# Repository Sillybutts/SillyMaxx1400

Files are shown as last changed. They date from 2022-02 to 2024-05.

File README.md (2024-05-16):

# SillyMaxx 1400

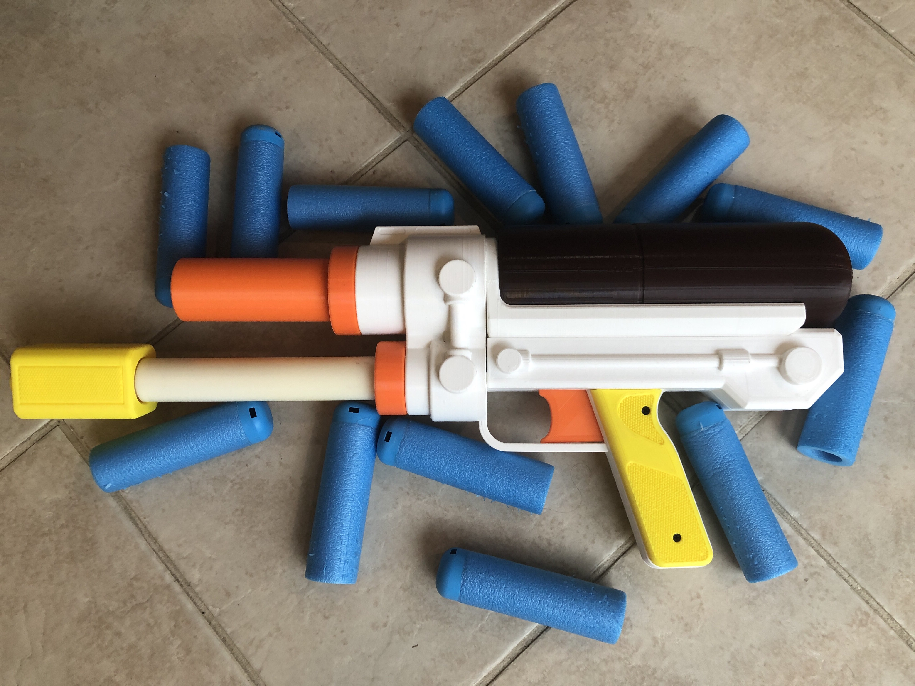
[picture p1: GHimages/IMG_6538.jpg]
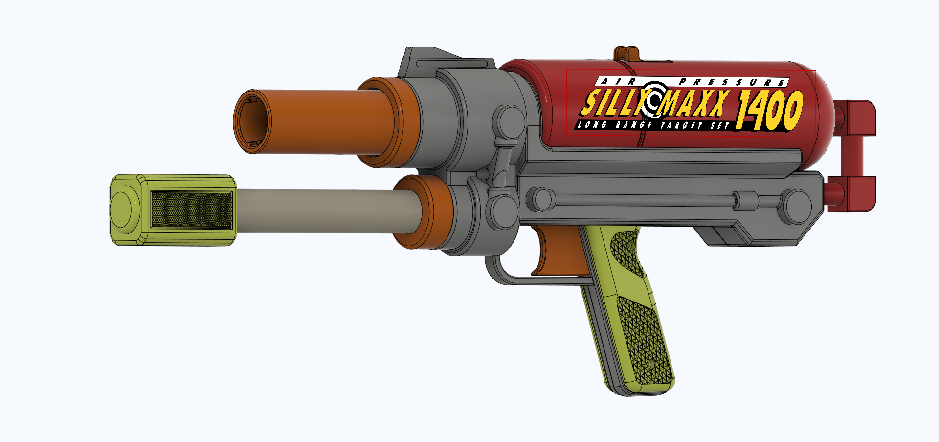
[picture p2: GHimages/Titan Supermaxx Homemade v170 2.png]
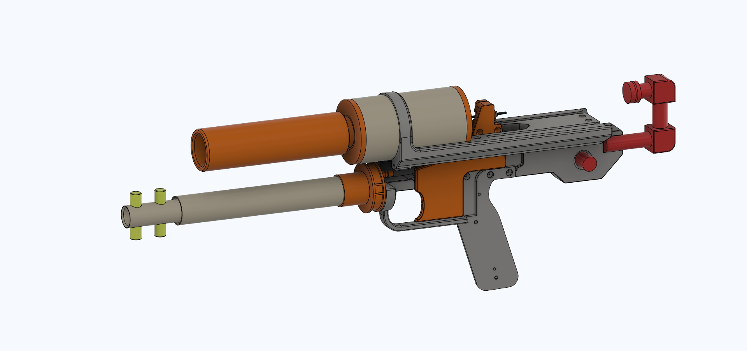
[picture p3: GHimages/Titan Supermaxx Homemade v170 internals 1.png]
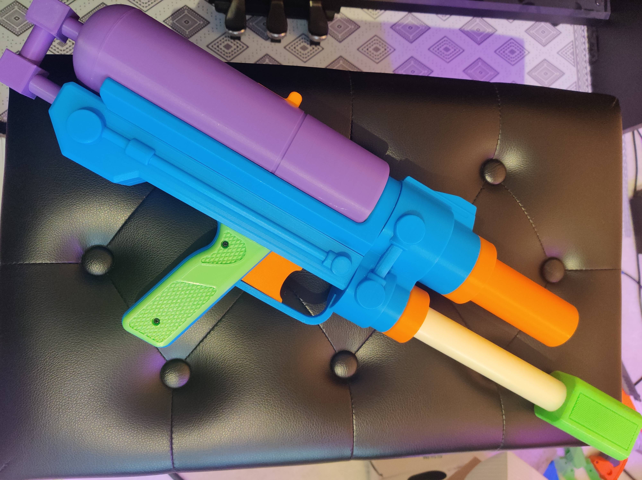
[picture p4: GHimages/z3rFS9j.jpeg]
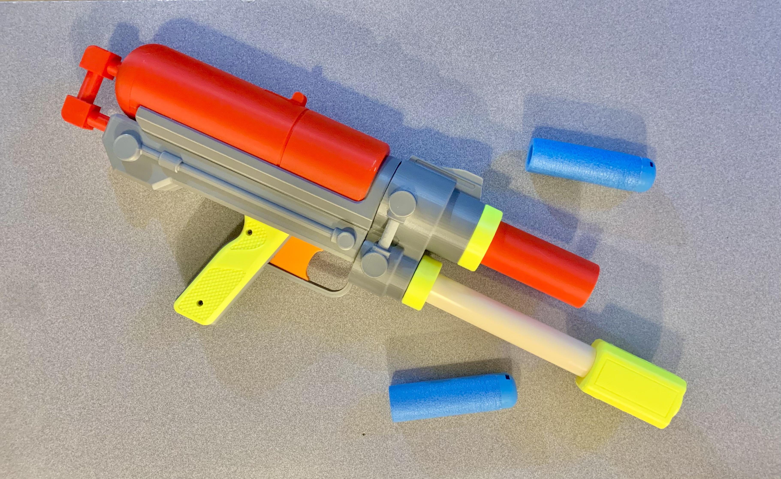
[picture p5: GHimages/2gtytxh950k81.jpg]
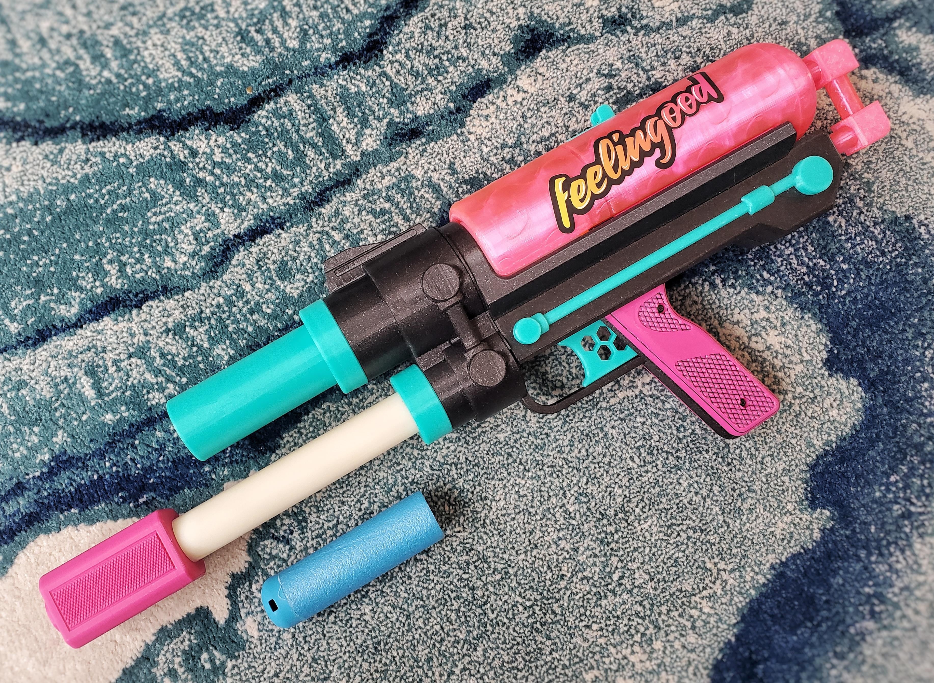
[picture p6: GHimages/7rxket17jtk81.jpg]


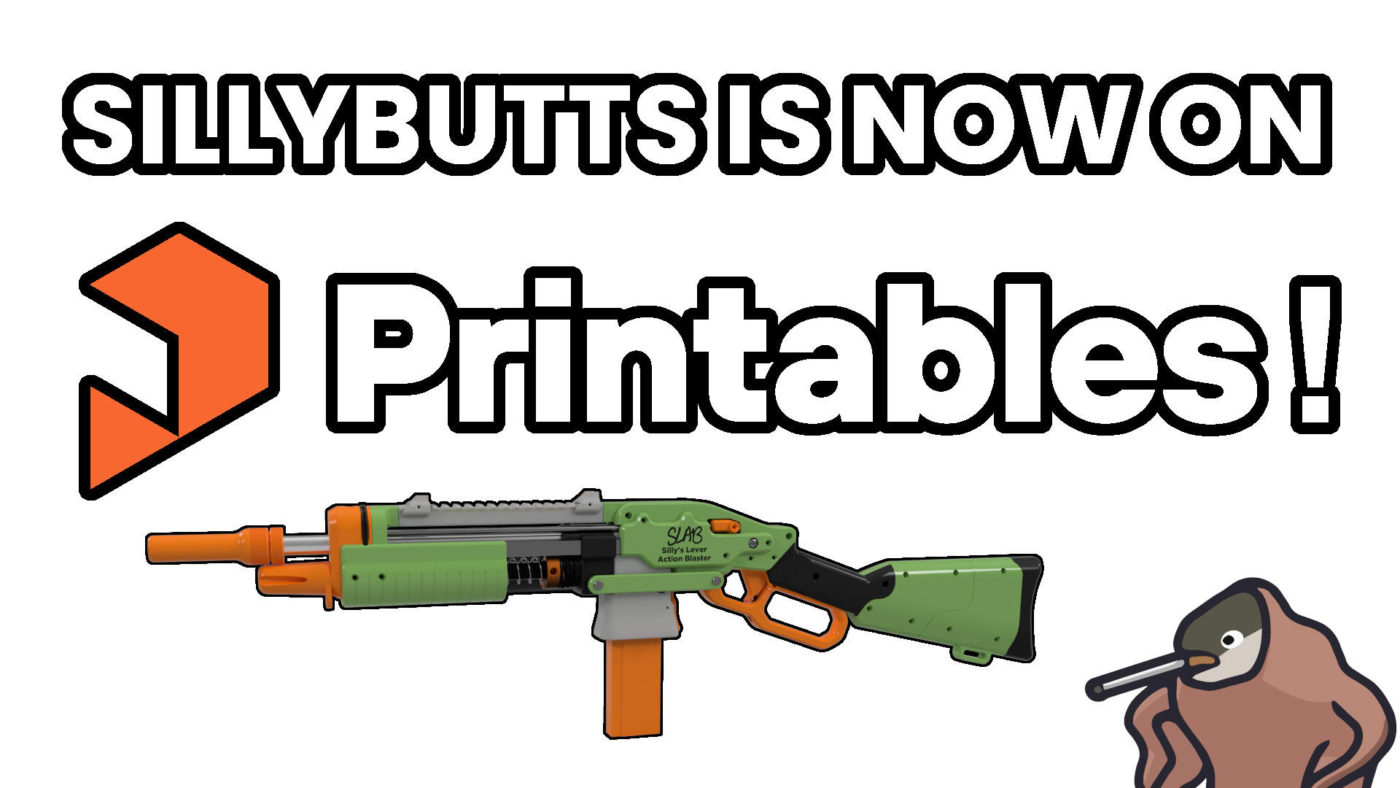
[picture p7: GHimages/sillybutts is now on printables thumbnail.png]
Printables Button


## I ALSO UPLOAD TO PRINTABLES https://www.printables.com/model/876191-sillymaxx-1400-nerf-titan-reshell

### Changelog:
4/14/22: Added a split version of BodyBlockC. There is now BodyBlockC, BodyBlockCFront, and BodyBlockCBack.

## Description

Basic assembly guide: https://www.youtube.com/watch?v=TCJiuXc-gHQ

1 minute firing demo: https://www.youtube.com/watch?v=Evi2LHyZtMM

1 minute blaster overview: https://www.youtube.com/watch?v=Qa94QIY8Uhg

The hall of finished blasters:
- Mine (Sillybutts) https://www.youtube.com/watch?v=uj7RobxyauM
- u/nick_la_plante https://www.reddit.com/r/Nerf/comments/t17dpy/finally_got_around_to_assembling_my_own/
- u/djnobility https://www.reddit.com/r/Nerf/comments/t4f6s7/the_sillymaxx_1400_has_me_feeling_good/
- u/Shaznazabbadaz https://www.reddit.com/r/Nerf/comments/t68buf/my_sillymaxx_1400_inspired_by_the_90s_sm1500_5000/

The SillyMaxx 1400 is a homemade shell for the Nerf Titan air blaster. This design takes the air tank and air pump of the Titan, and puts it into a shell modelled after the Larami SuperMaxx 500 and Larami SuperMaxx 2000 (later called the Supermaxx 5000, produced by Nerf). 

## IF YOU WANT A STICKER FOR THE SIDE OF YOUR SILLYMAXX 1400, HERE YOU GO! https://www.redbubble.com/i/sticker/SillyMaxx-1400-Logo-by-Sillybutts/103172289.EJUG5 I recommend the Medium (5.5 x 1 inch) transparent sticker

The main idea for the blaster was that Titans are a semi-common, high power air blaster, that most people don't use due to their size and ammo unavailability. This design makes the Titan smaller, and lets you use many different types of common ammo, like full length darts, short darts, Mega XL, Mega, and Rival. 

MegaXL Performance using the Mega XL barrel: 115 avg out of Trivictus barrel, 12 pumps (stock Titan OPRV goes off at 12).

You can still use original Titan missiles/rockets with the included barrels, they slide over the outside of the barrel.

## Performance

Performance numbers contributed by Shaznazabbadaz!

Maximum pumps before the stock Titan over pressure release valve kicks off. These numbers can be significantly increased with a plugged pump.

- MegaXL- 105FPS. 
- 5 Full Lengths- 115FPS 
- 5 half darts- 120FPS 
- 10 half darts- 95-100FPS
- Triple Rival- 115FPS 
- Mega- 120FPS

## Hardware, Stickers, and Assembly

This blaster is not as cleanly assembled as my other designs. It was mainly made as a personal project. It is still not *hard* to build, but its certainly more involved than building a printed blaster straight from a hardware kit. There is glue.

Hardware:
- 1x Titan Tank and pump
- 26x Titan shell screws, or 4-40 screws. You don't need all of them for the blaster to be sturdy, but the holes are there anyway.
- 2x "longer" screws. These are for securing the Frontblock to the rest of the blaster. I used #4 x 1/2 inch pan head phillips screws. You could probably use the longest screws from the original Titan's shell. Basically, it needs to be a nice long, coarse thread screw that fits in the two holes in the front of the Frontblock. 
- Glue. I used Super Glue / Cyanoacrylate glue.

You can also buy a SillyMaxx 1400 logo sticker to put on the side of the blaster from my RedBubble. I recommend the Medium (5.5 x 1 inch) transparent sticker https://www.redbubble.com/i/sticker/SillyMaxx-1400-Logo-by-Sillybutts/103172289.OP1U7

Here is my video, explaining how to assemble the blaster: https://youtu.be/TCJiuXc-gHQ

TlDr, 
- screw together the things with screw holes, glue together the things without screw holes. 
- Attaching the Faux tank needs no screws or glue, it just dovetails on. 
- Don't glue the Faux tank's back "pipe" into the body of the blaster, because then you can't remove the Faux tank to do any tank maintenance if need be. 
- The tank and pump are NOT glued or screwed directly into, they are just friction fit and sandwhiched into the blaster. 
- The trigger should only really be used with the Faux tank in place, or else it will bend slightly up, slightly bending the tank's release pin, causing leaks. 
- The front block is screwed in with two screws. THESE SHOULD BE THE LONGEST SCREWS FROM THE TITAN SHELL, OR SOME OTHER LONG SCREW. I used #4 x 1/2in sheet metal screws from my local hardware store.

## Tank and Pump Minimization

To be used in the SillyMaxx 1400 design, a stock Titan tank and Titan pump need to be slightly minimized. These minimizations do not increase the power of the blaster, they just make the tank and pump slightly slimmer. 

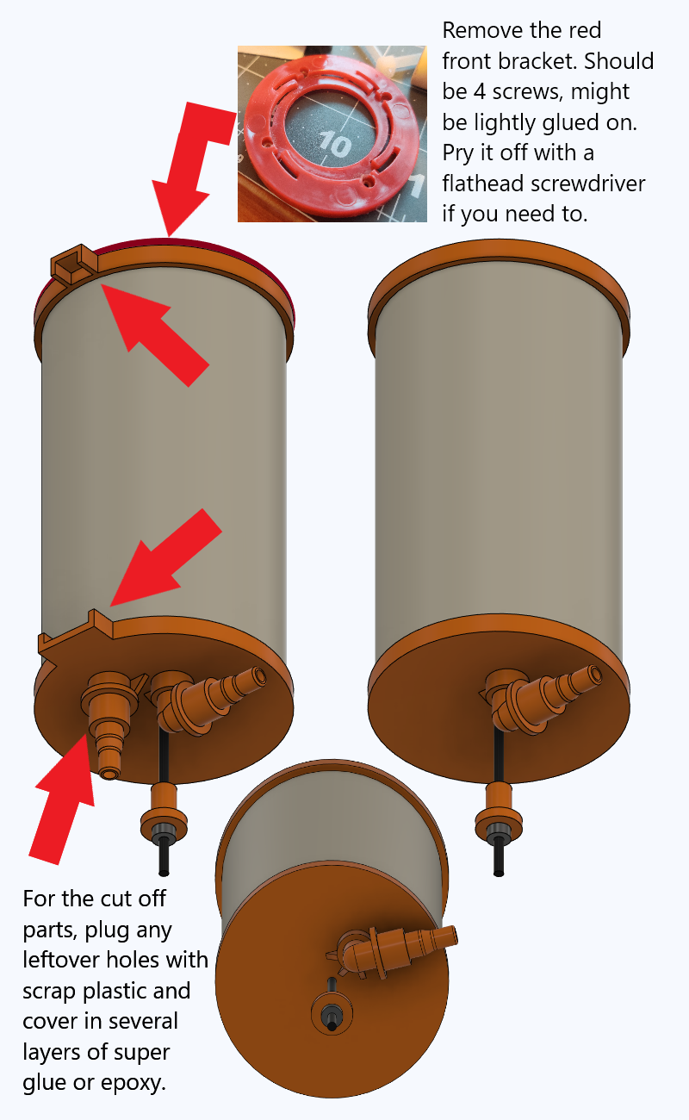
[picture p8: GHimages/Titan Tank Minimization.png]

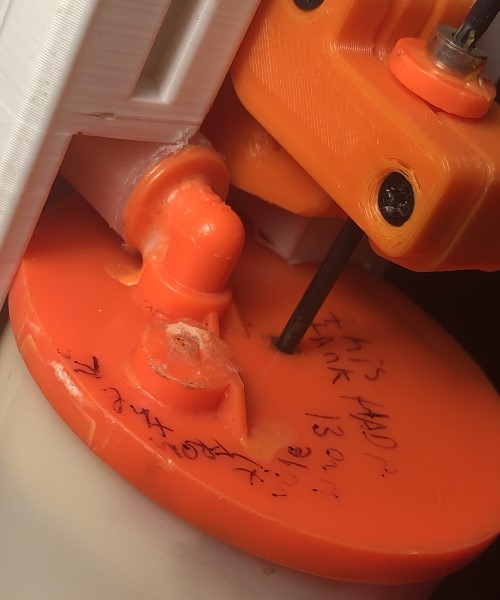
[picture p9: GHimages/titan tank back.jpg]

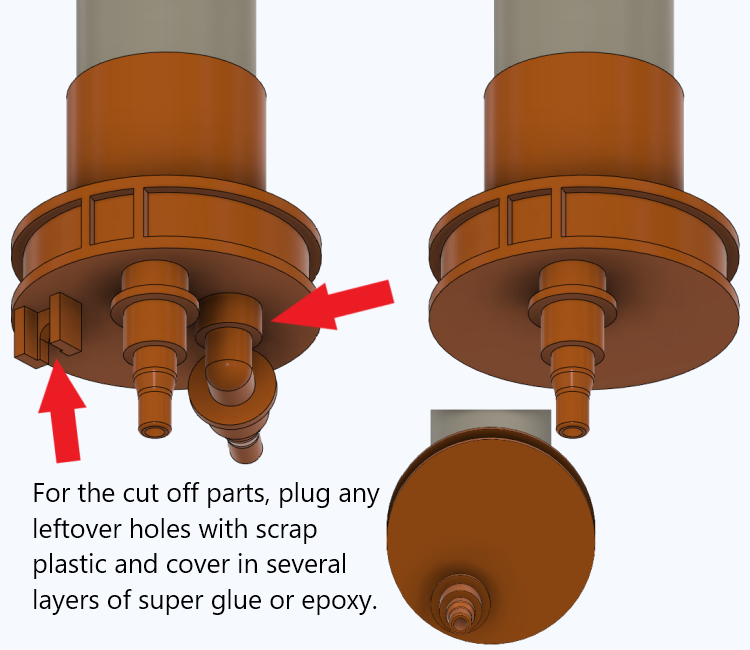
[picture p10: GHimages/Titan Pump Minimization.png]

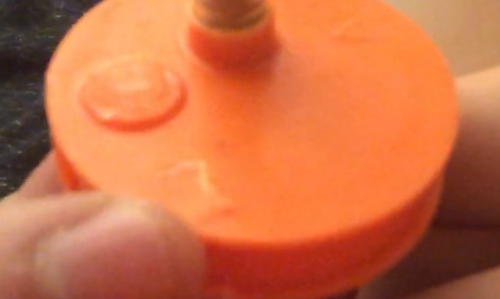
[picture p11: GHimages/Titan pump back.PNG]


## Print Info

All STLs were exported in print orientation. STEP and F3D are also provided.

The minimum build volume for your printer is 210mm x 210mm x 210mm if you use the split version of BodyBlockC. The minimum for the unsplit BodyBlockC is 210mm x 210mm x 215mm. The blaster was designed to fit on Ender 3 printers, or bigger.

Some parts need brims, a lot of parts need supports. This blaster is NOT as cleanly printed as my other designs.

BodyBlockC MUST BE PRINTED VERTICALLY, WITH THE RING AGAINST THE PRINT BED. If this isn't done, then the ring will be fragile and break off.

I recommend rafts for the BodyBlockA and BodyBlockB parts, to keep them straight, and to make the supports easier to remove. I use Cura tree supports. 

The smaller parts (Trigger bits, tank pipe parts, the front cover rings, modules for the top of the faux tank, grip panels etc) should be printed at high infill. I did them at 20% gyroid infill, 4 walls.

The barrels included in the fileset should be printed at 5 walls, at least 20% infill. 

The large parts (BodyBlockA,B,C, Faux Tank, Frontblock, etc) and the pump grip can be printed at lower infill and wall count. I did them at 5-10% gyroid infill, 3 walls. 

## Misc.

**If you make any of my designs, I'd love to see yours! Feel free to message me on Discord (Sillybutts#5905) or tag me on a post on Reddit (u/SillyTheGamer).**

**If you are having issues with any of my designs, let me know on Discord (Sillybutts#5905) or Reddit (u/SillyTheGamer).**

**If you wish to print and sell this item, please contact me for licensing. I can be reached on Discord (Sillybutts#5905) or Reddit (u/SillyTheGamer).**

<br />This work is licensed under a <a rel="license" href="http://creativecommons.org/licenses/by-nc-sa/4.0/">Creative Commons Attribution-NonCommercial-ShareAlike 4.0 International License</a>.

## If you like what I do, please consider supporting me!

**I don't charge for my files, so any donations or merch purchases would be greatly appreciated!**

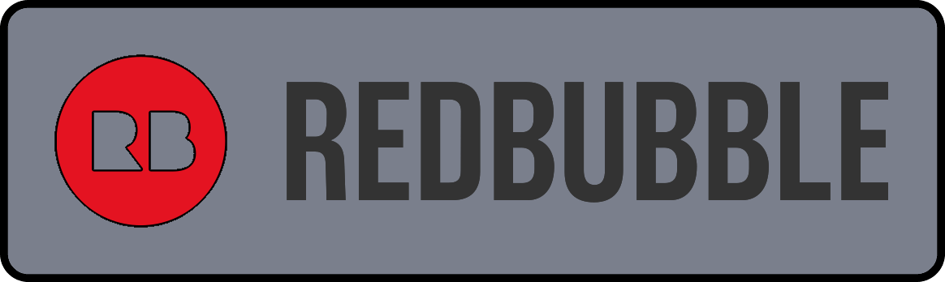
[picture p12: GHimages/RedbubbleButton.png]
RedBubble Button
 https://www.redbubble.com/people/Sillybutts/shop RedBubble full of fun Nerf-y sticker and merch designs!  

<a href="https://www.patreon.com/sillybutts/">Patreon Button</a> https://www.patreon.com/sillybutts Monthly donations

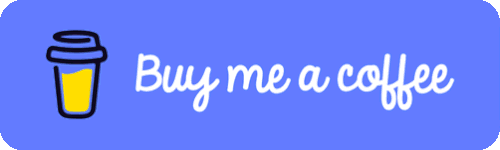
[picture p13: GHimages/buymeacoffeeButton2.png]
BuyMeACoffee Button
 https://www.buymeacoffee.com/sillybutts One-time donations

And here's my Etsy: https://www.etsy.com/shop/sillybuttsshop

## Images


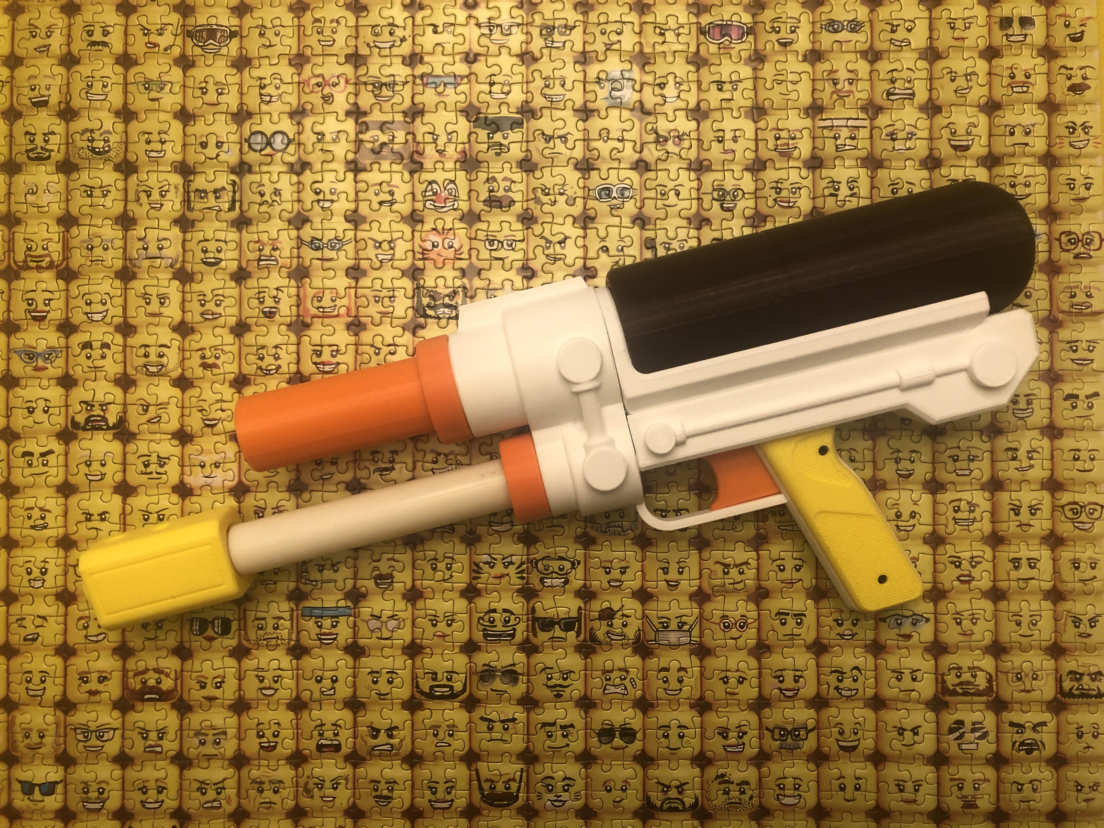
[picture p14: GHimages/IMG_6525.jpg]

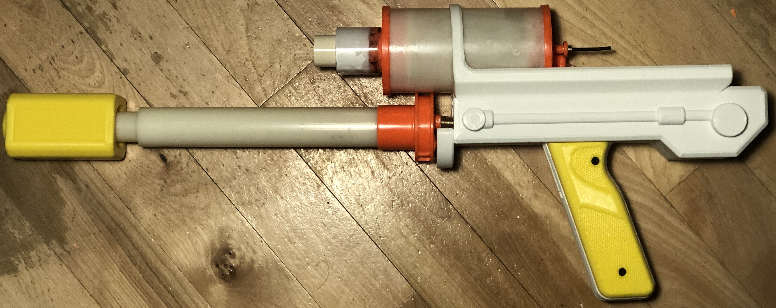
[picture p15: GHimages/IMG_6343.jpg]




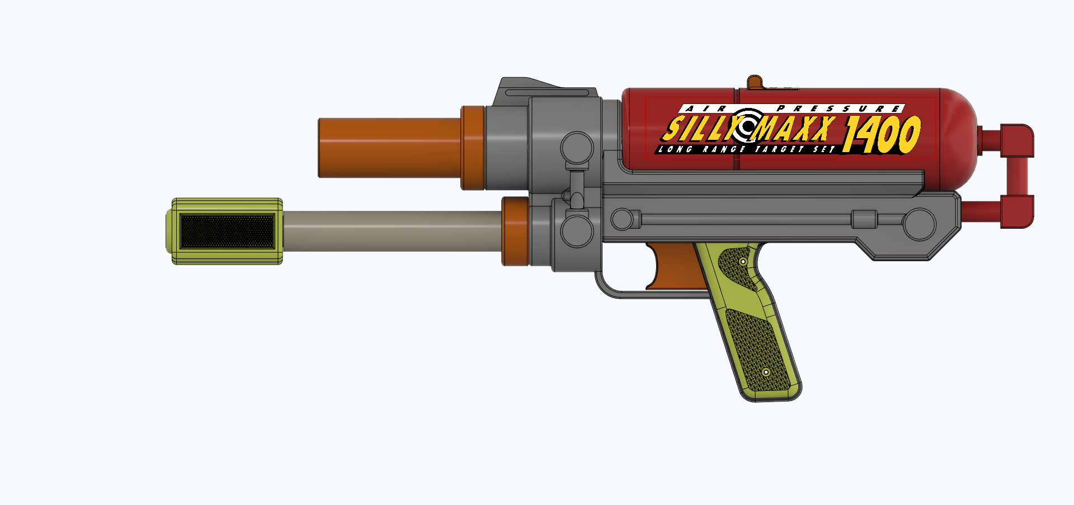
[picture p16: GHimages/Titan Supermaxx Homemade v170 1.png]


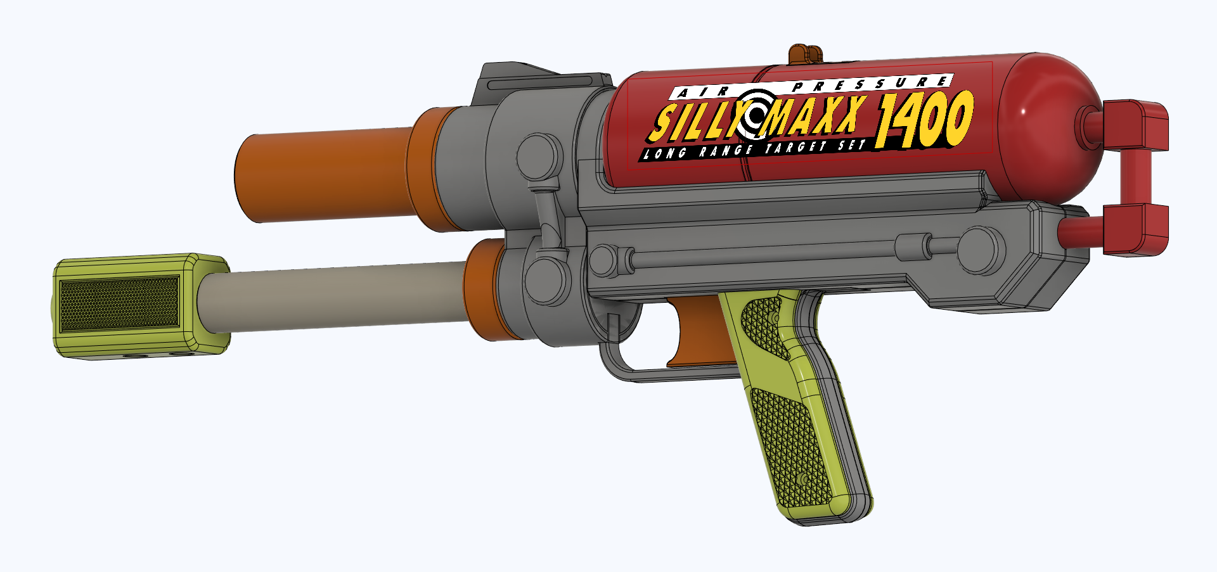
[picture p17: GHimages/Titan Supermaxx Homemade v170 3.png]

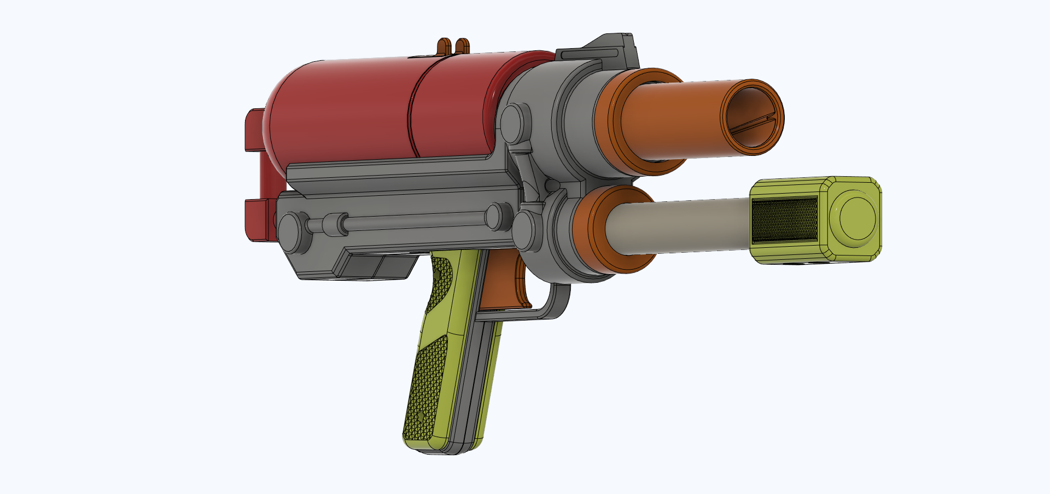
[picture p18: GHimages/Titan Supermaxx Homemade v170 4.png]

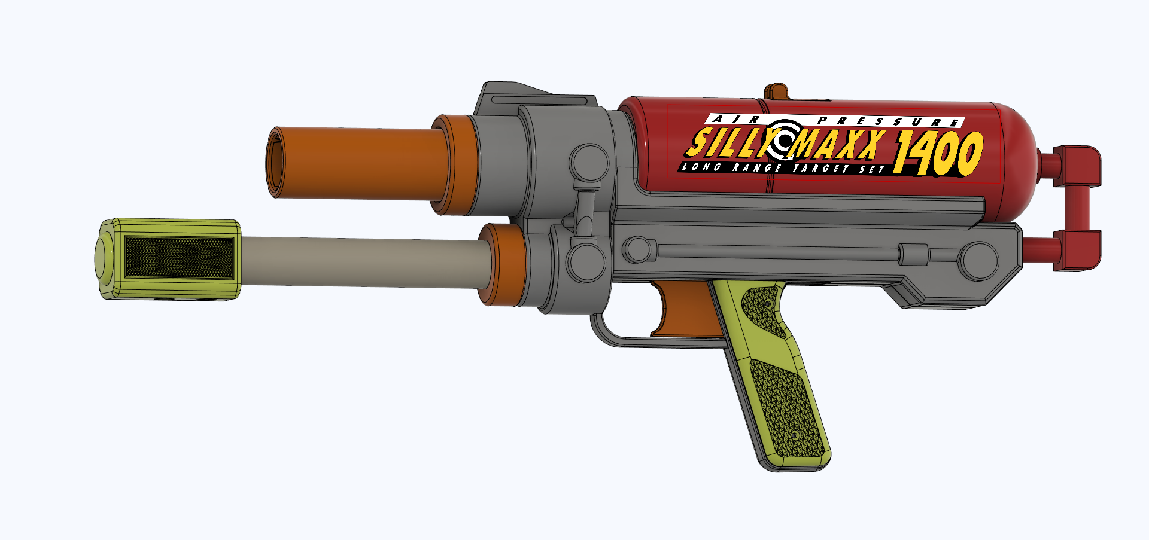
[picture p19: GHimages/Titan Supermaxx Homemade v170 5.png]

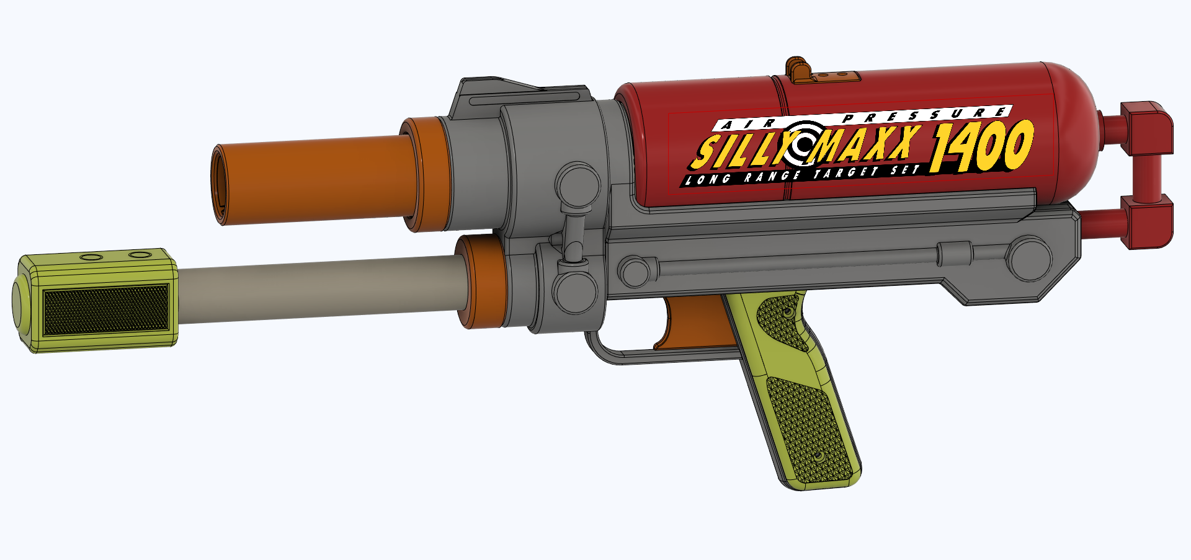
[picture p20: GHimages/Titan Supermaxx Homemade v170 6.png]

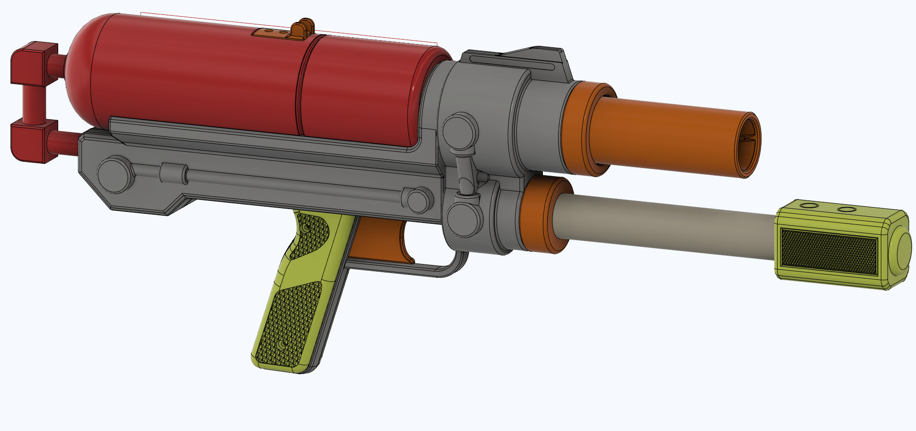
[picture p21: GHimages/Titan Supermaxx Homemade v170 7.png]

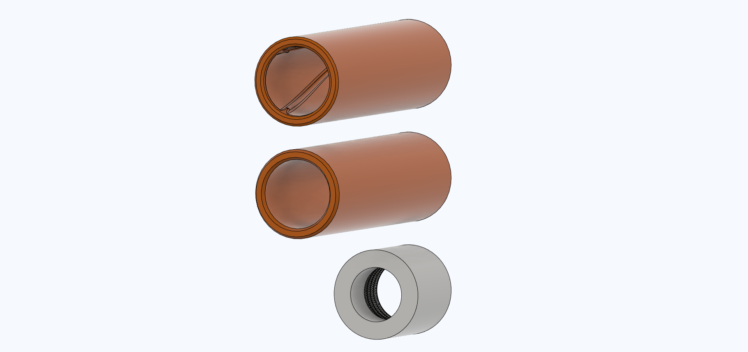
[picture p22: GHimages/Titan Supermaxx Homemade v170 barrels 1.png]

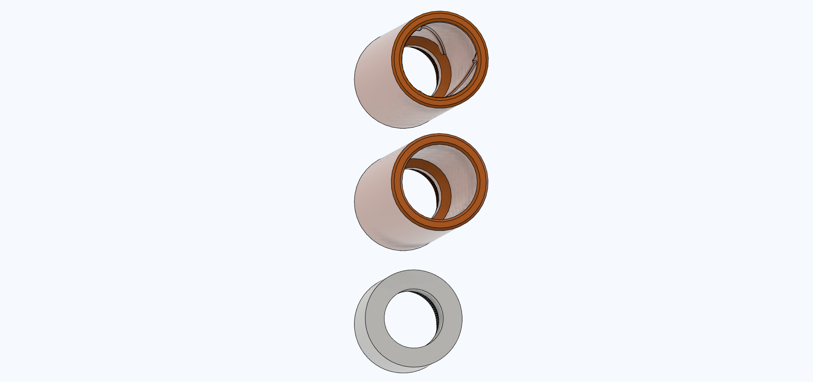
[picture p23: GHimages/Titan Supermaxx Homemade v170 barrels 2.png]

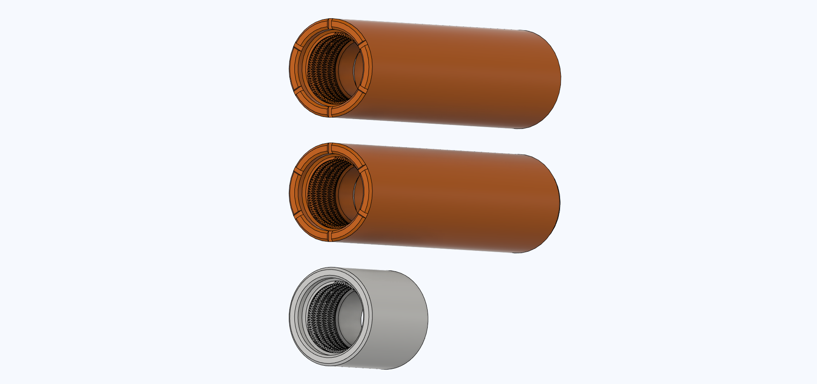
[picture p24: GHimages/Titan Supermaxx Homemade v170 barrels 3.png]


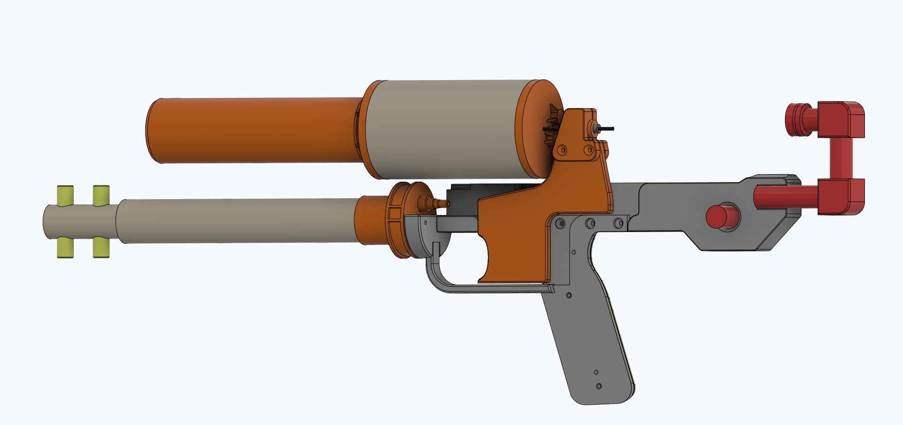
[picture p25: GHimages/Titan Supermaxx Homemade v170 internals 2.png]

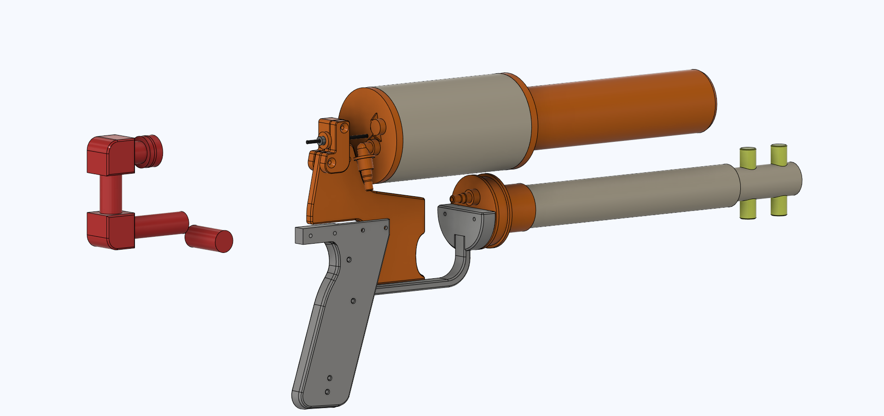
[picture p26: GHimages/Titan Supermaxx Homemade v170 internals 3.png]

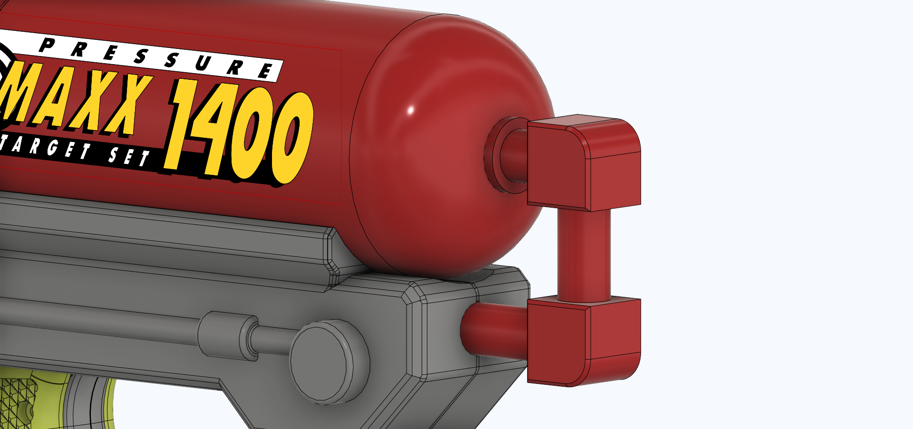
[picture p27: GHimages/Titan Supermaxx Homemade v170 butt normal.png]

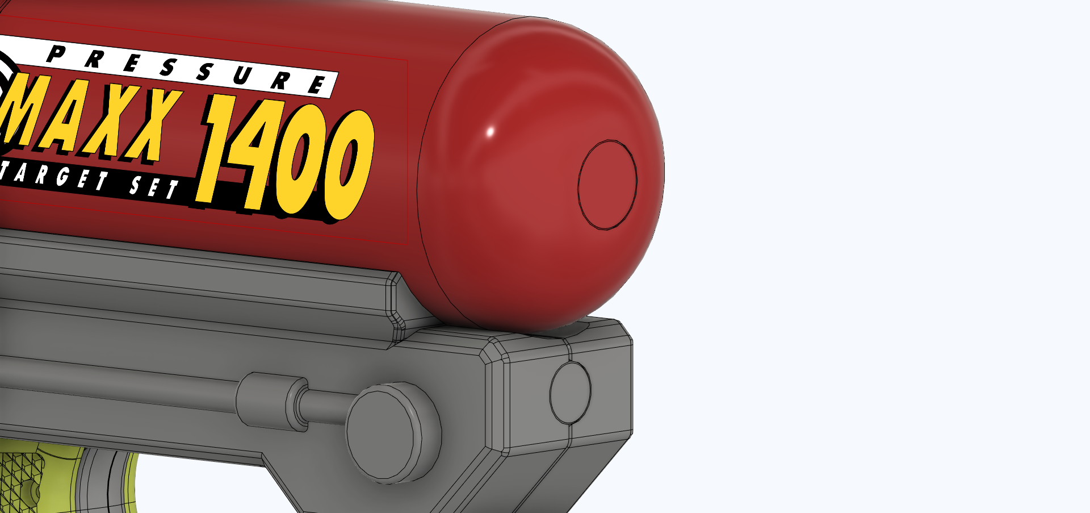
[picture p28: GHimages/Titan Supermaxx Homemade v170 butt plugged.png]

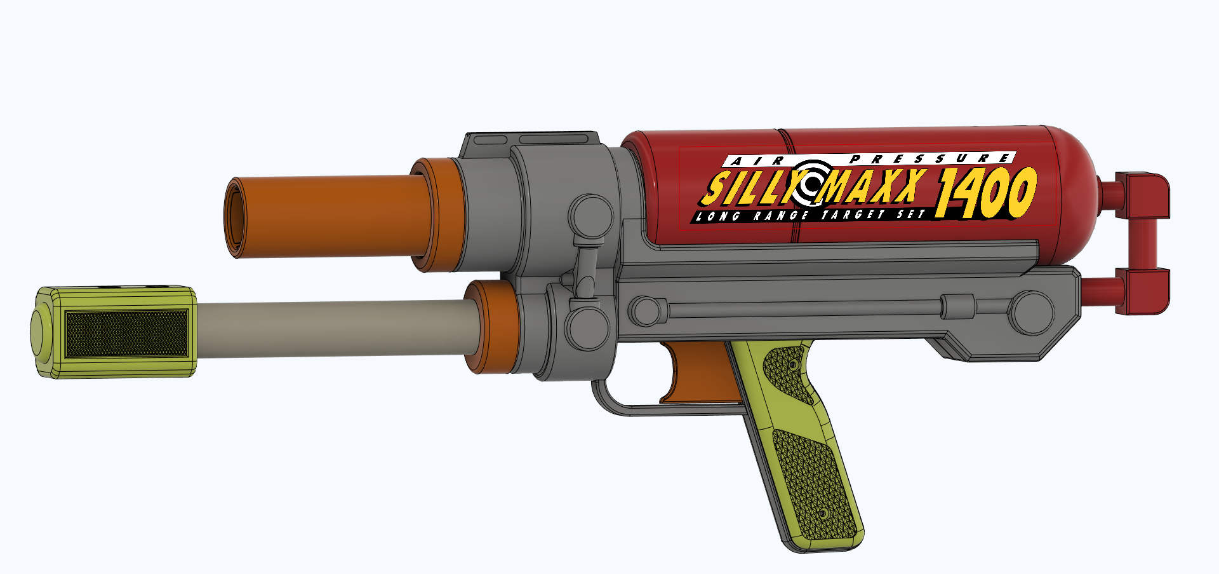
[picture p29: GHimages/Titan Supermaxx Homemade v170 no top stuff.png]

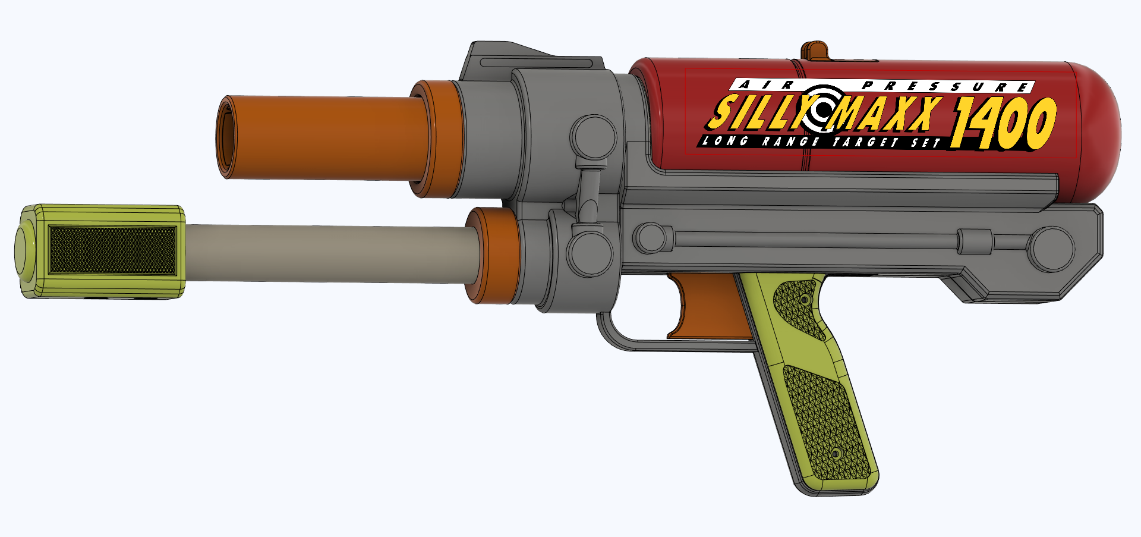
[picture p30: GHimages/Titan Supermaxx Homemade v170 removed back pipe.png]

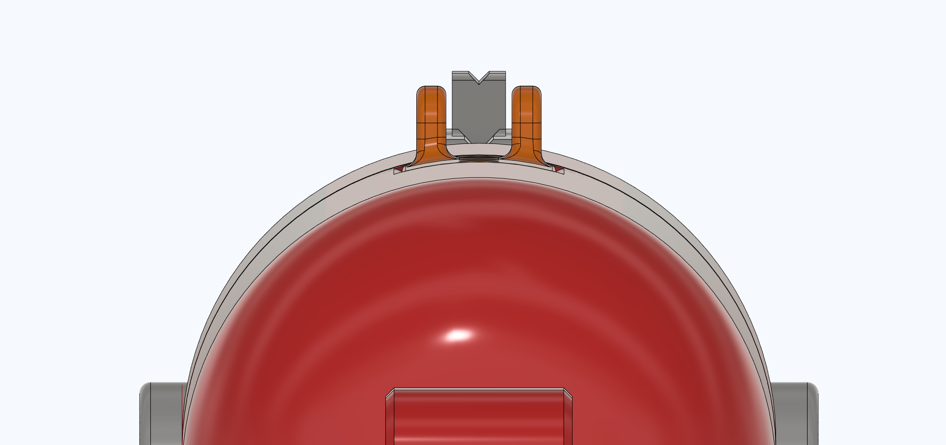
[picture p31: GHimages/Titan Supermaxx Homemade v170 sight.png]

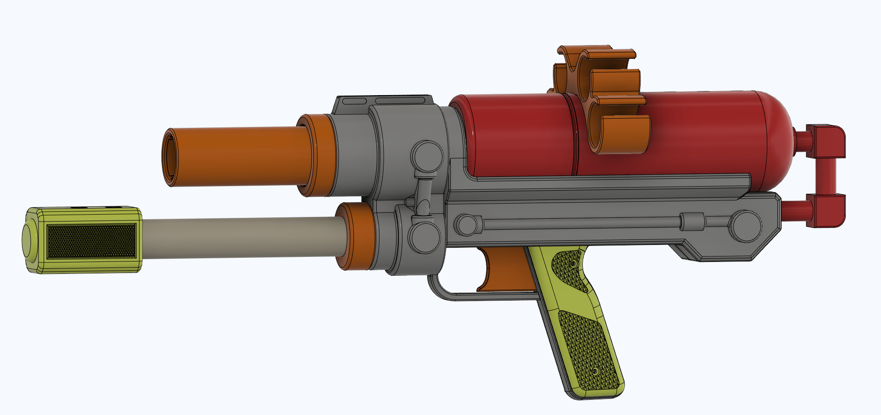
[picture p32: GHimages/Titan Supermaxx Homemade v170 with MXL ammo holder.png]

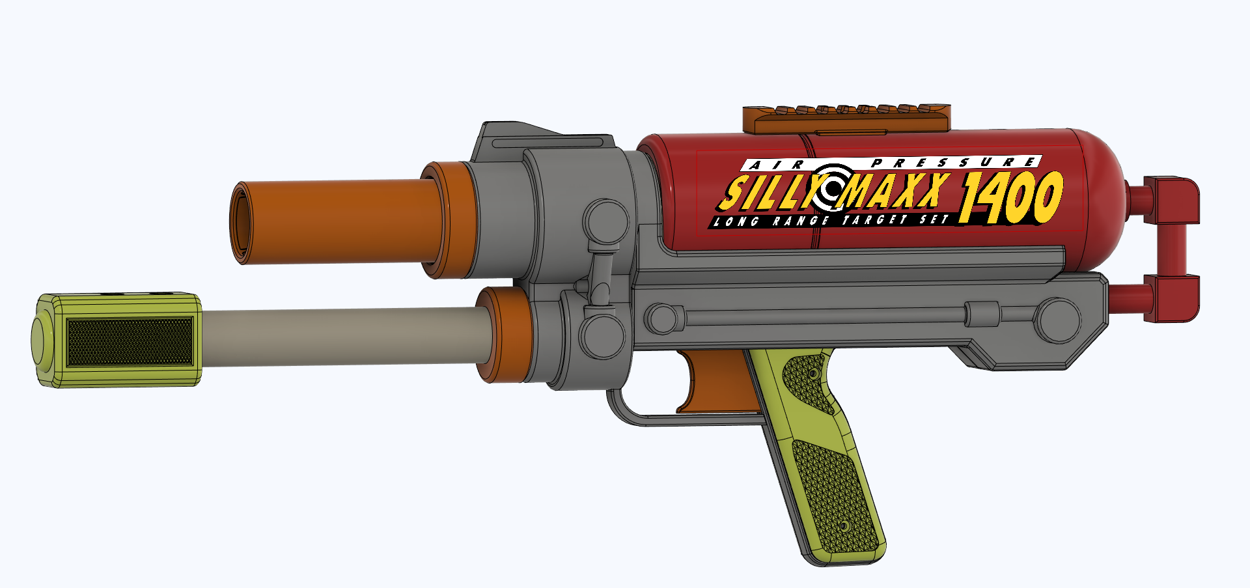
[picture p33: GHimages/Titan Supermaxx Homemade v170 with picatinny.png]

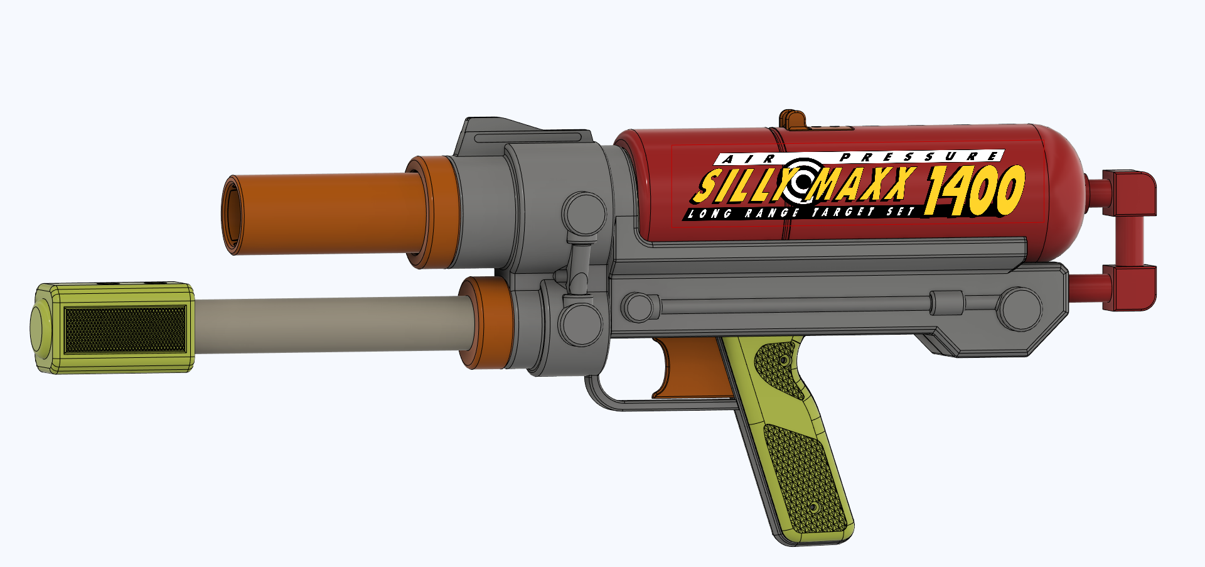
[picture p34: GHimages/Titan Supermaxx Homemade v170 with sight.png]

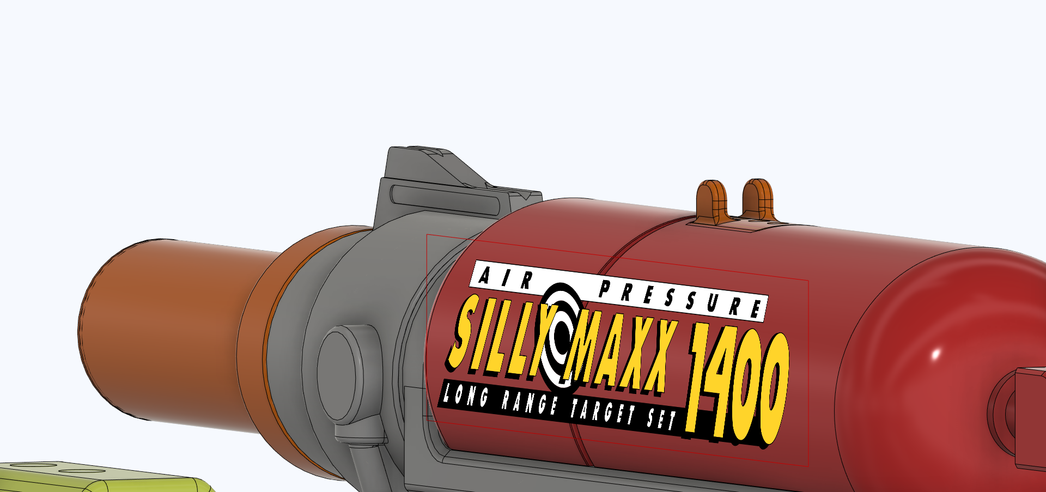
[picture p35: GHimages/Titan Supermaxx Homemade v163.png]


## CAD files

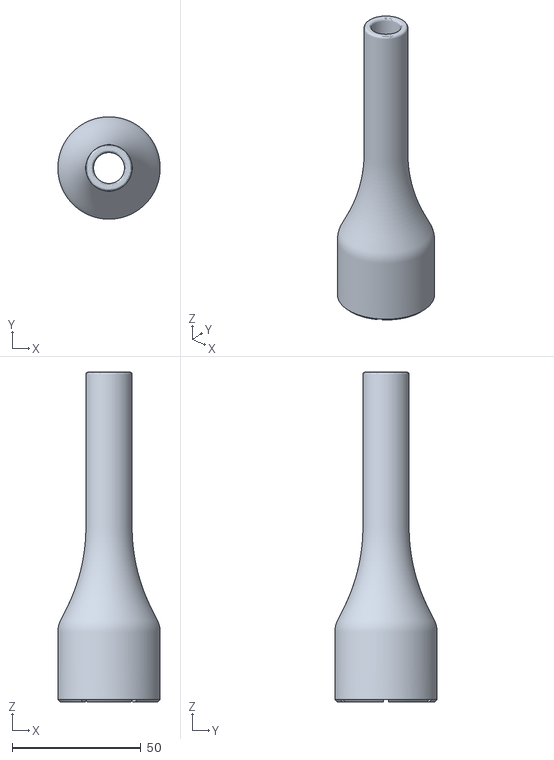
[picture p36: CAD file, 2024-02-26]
STLs/Barrels/Demolisher Missile Barrel.stl
39.8 x 39.8 x 128.3

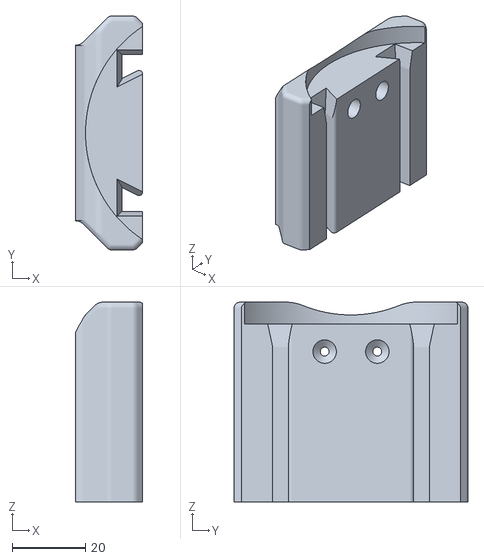
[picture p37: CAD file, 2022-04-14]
STLs/Gray/BodyBlockCBack.stl
18.4 x 64.0 x 54.6

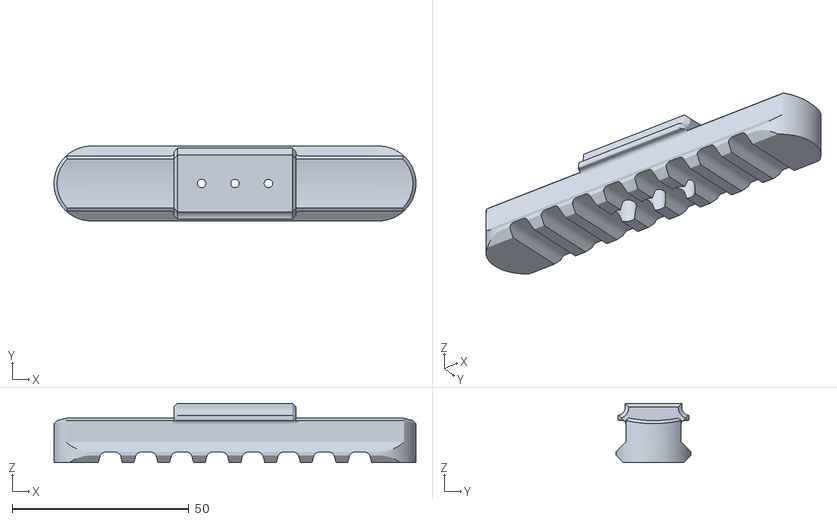
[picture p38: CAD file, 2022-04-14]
STLs/Orange/Attachments for top of Faux Tank/Picatinny Rail.stl
102.5 x 21.2 x 16.8

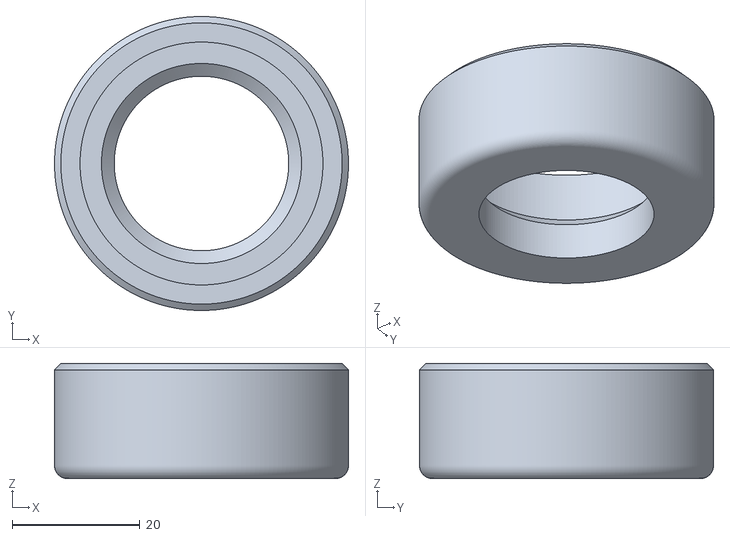
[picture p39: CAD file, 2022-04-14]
STLs/Orange/Bottom Front Cap.stl
46.0 x 46.0 x 18.0

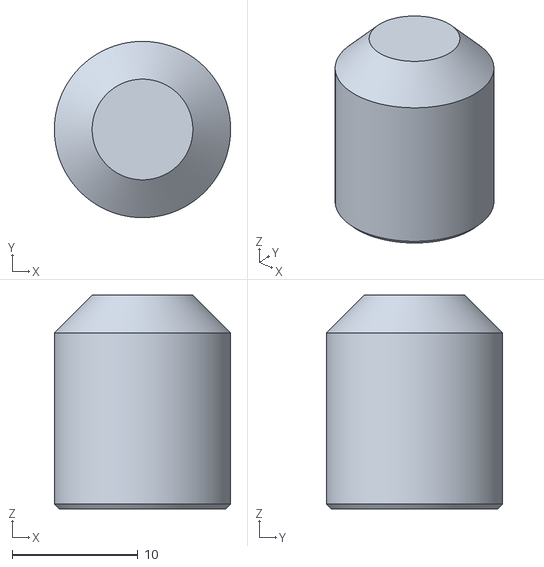
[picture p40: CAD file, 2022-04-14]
STLs/Red/Back pipe removal plugs/BackTubeCOVERBOTTOM.stl
14.0 x 14.0 x 17.0

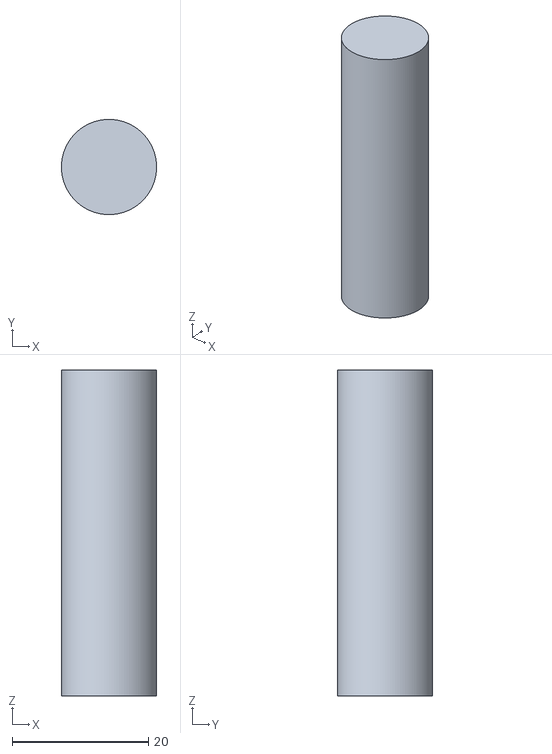
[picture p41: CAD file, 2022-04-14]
STLs/Red/BackTube3.stl
14.0 x 14.0 x 47.9

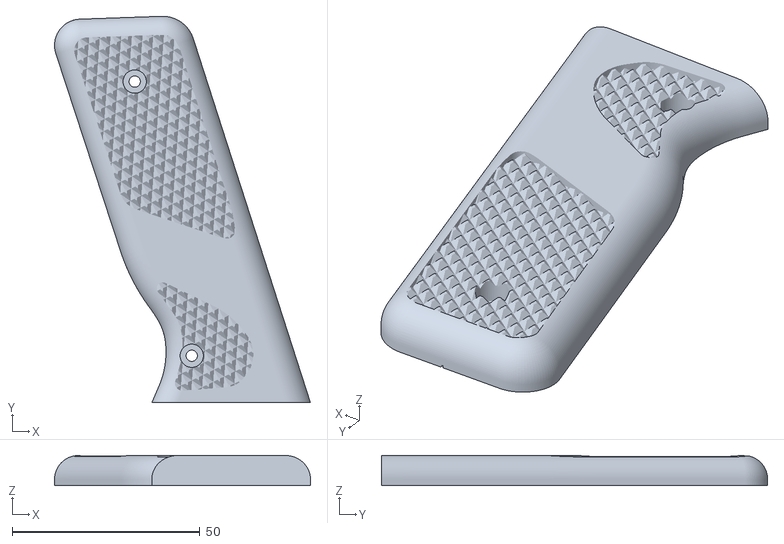
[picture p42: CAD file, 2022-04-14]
STLs/Yellow/L Grip Panel v3.stl
68.2 x 102.9 x 8.00

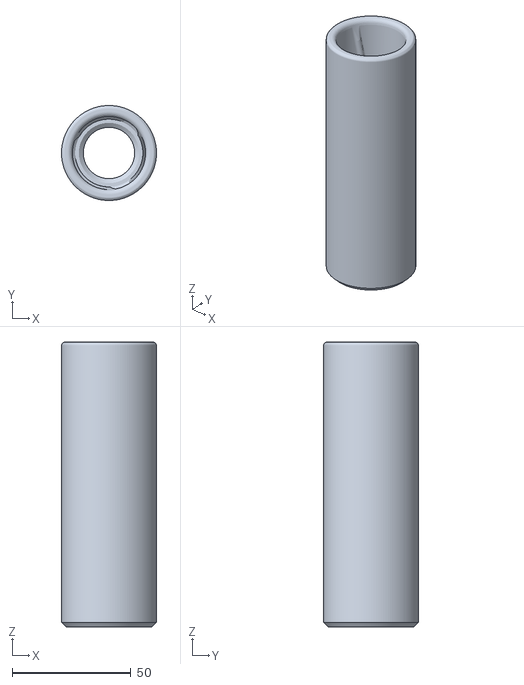
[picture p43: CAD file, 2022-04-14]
STLs/Barrels/halfinchPVC trivictus.stl
40.0 x 40.0 x 120.0

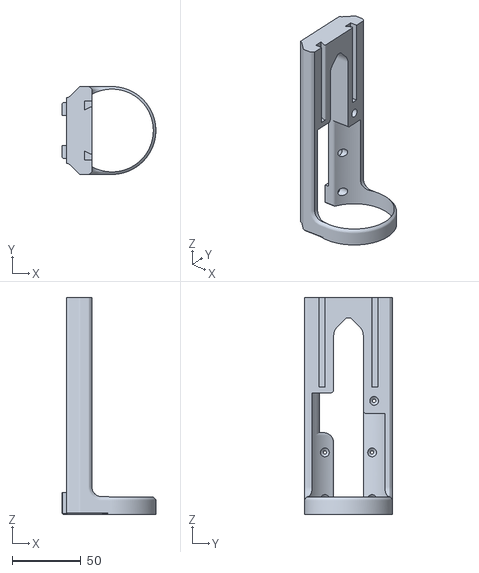
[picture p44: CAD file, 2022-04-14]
STLs/Gray/BodyBlockCFront.stl
68.3 x 64.1 x 158.2

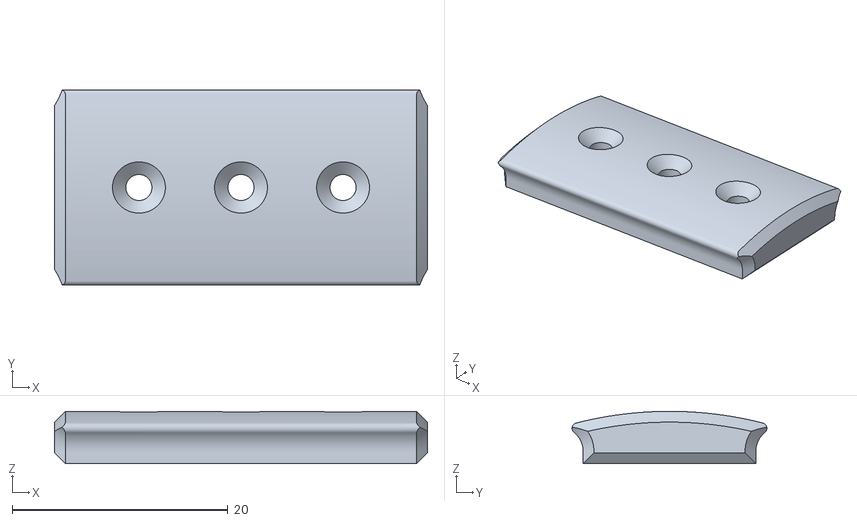
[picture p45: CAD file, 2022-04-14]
STLs/Orange/Attachments for top of Faux Tank/BlankTopAttachment.stl
34.5 x 18.0 x 4.85

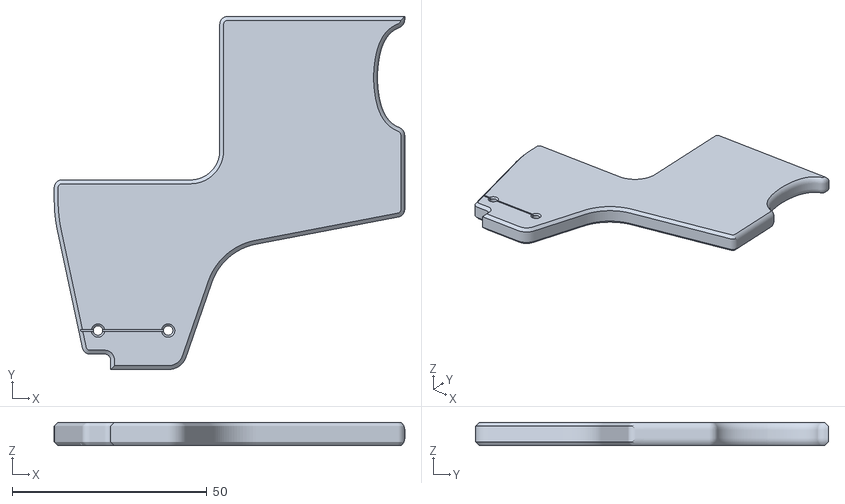
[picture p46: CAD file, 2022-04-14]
STLs/Orange/TriggerA.stl
89.9 x 90.5 x 6.00

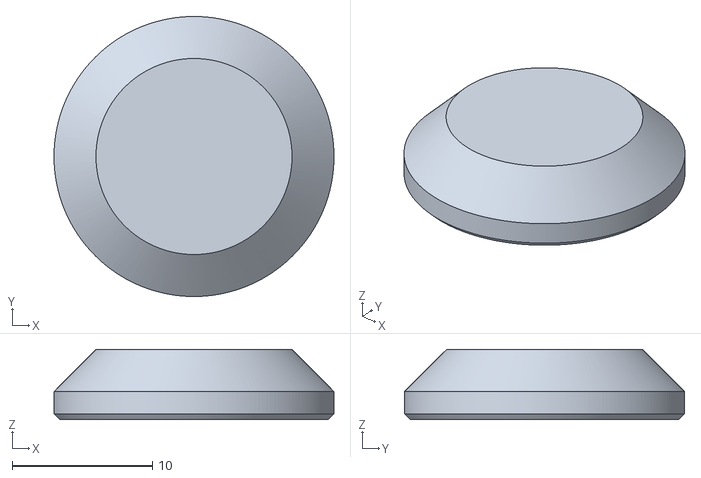
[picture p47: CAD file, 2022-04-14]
STLs/Red/Back pipe removal plugs/BackTubeCOVERTOP.stl
20.0 x 20.0 x 5.00

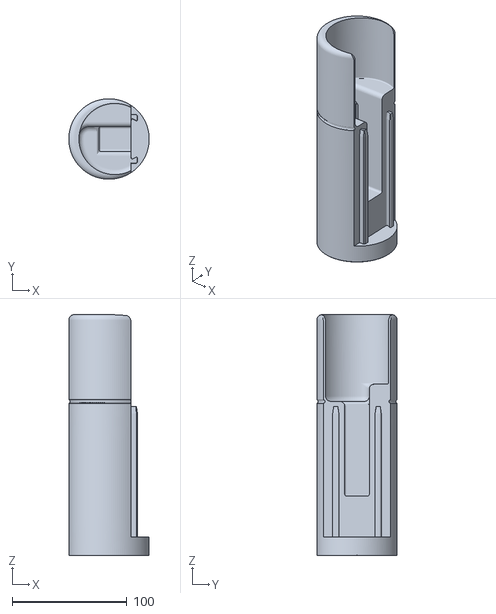
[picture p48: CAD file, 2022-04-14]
STLs/Red/Faux Tank NoTopSlot A.stl
70.0 x 70.0 x 209.8

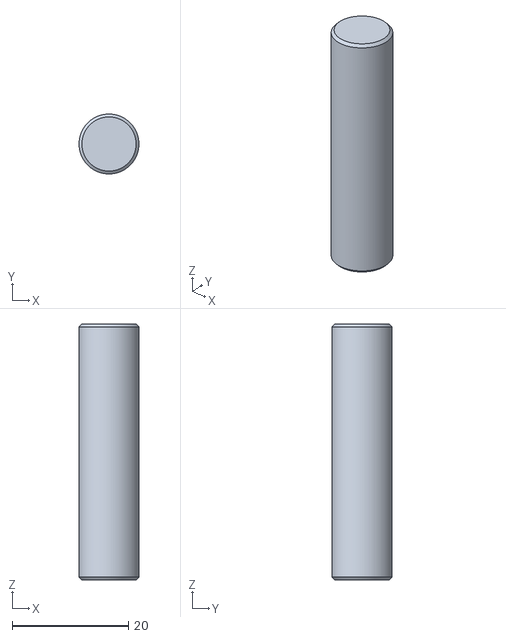
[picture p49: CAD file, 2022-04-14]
STLs/Yellow/PGpinPRINTTWO.stl
10.3 x 10.3 x 44.0

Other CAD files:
STLs/Barrels/5x Elite.stl
STLs/Gray/Trigger Guard.stl
STLs/Orange/Attachments for top of Faux Tank/TopSight.stl
STLs/Orange/TriggerB.stl
STLs/Barrels/3x Elite.stl
STLs/Barrels/3x Rival.stl
STLs/Barrels/MXL Smooth Bore.stl
STLs/Barrels/MXL Trivictus.stl
STLs/Barrels/Mega.stl
STLs/Barrels/halfinchPVC SMOOTH.stl
STLs/Gray/Back Cover.stl
STLs/Gray/BodyBlockA.stl
STLs/Gray/BodyBlockB.stl
STLs/Gray/BodyBlockC.stl
STLs/Gray/FrontBlock NoSight.stl
STLs/Gray/FrontBlock wSight.stl
STLs/Gray/GripFrameA.stl
STLs/Gray/GripFrameB.stl
STLs/Gray/Sling Point.stl
STLs/Gray/SmallCover.stl
STLs/Orange/Attachments for top of Faux Tank/MXL Ammo Holder.stl
STLs/Orange/Top Front Cap.stl
STLs/Orange/TriggerC.stl
STLs/Red/BackTube1.stl
STLs/Red/BackTube2PRINTTWO.stl
STLs/Red/BackTube4PRINTTWO.stl
STLs/Red/Faux Tank B.stl
STLs/Red/Faux Tank wAttachmentSlot A.stl
STLs/Yellow/PumpGrip.stl
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
